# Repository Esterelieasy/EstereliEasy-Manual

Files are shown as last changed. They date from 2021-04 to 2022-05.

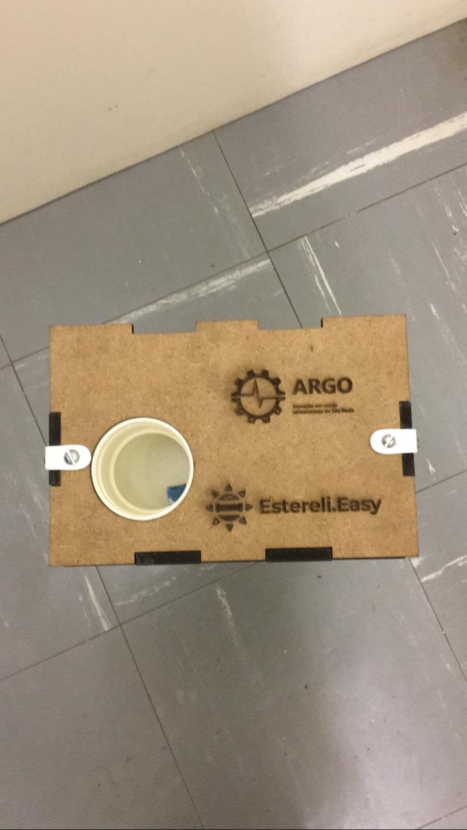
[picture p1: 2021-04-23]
Mídia/EstereliEasy3.jpeg

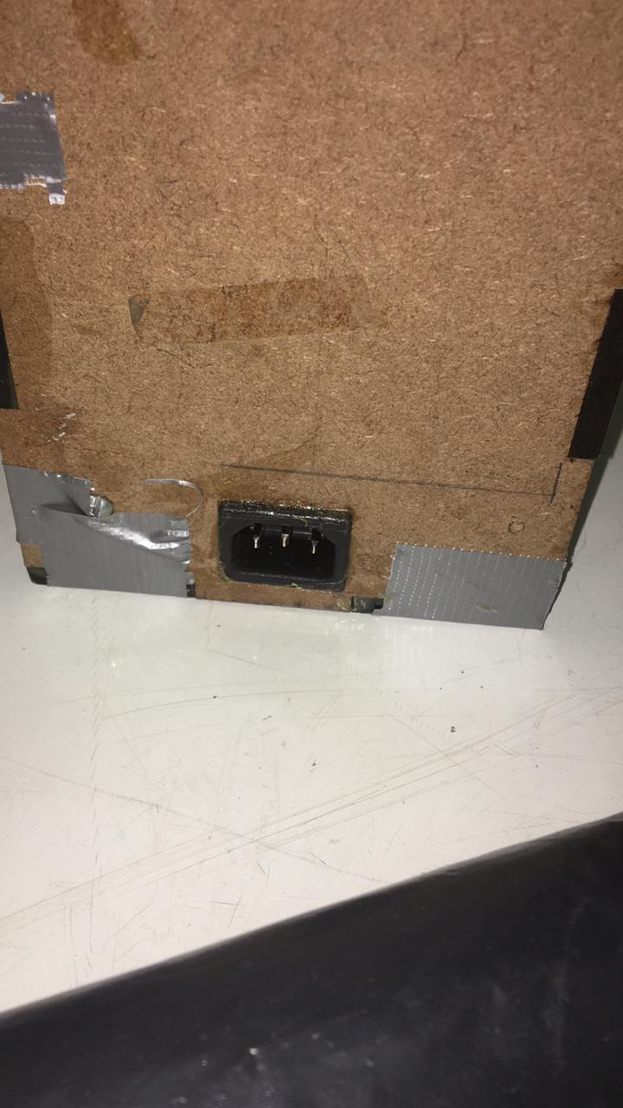
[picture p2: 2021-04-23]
Mídia/Esterelieasy4.jpeg

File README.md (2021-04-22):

# EstereliEasy-Manual
Repositório com informações de construção do nosso dispositivo.

Divisão das pastas:

* Arquivos - Cortadora: arquivos .dxf referentes às placas utilizadas para construção do equipamento.
* Parte Elétrica: imagens e arquivos referentes ao sistema eletrônico.
* Parte Mecânica: TO DO.
* Simulações: TO DO.
* Mídia: fotos e vídeos do protótipo.
* Manual: .pdf do Manual.

Link para conhecer o projeto: https://www.esterelieasy.com.br/

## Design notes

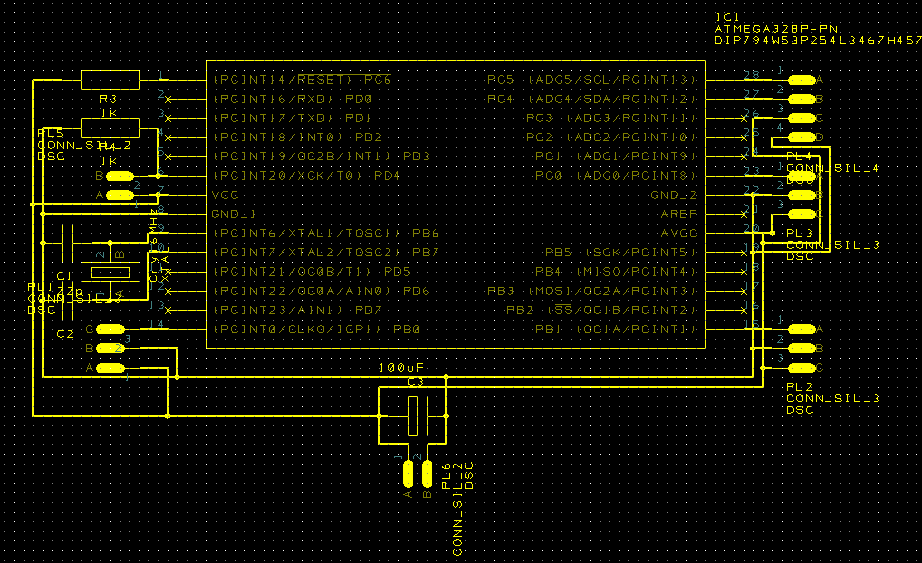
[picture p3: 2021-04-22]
Parte Elétrica/Captura de Tela (603).png

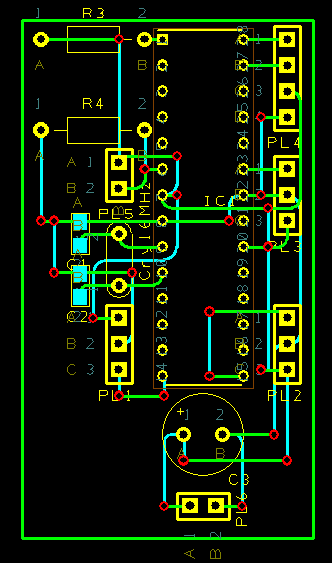
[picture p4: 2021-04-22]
Parte Elétrica/Captura de Tela (604).png

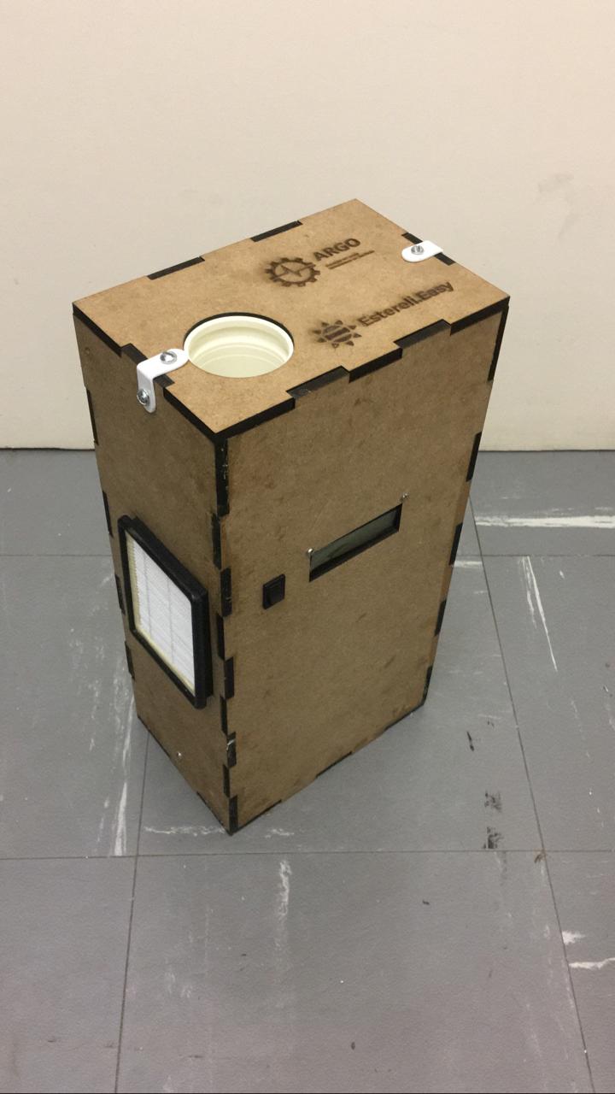
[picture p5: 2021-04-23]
Mídia/Esterelieasy1.jpeg

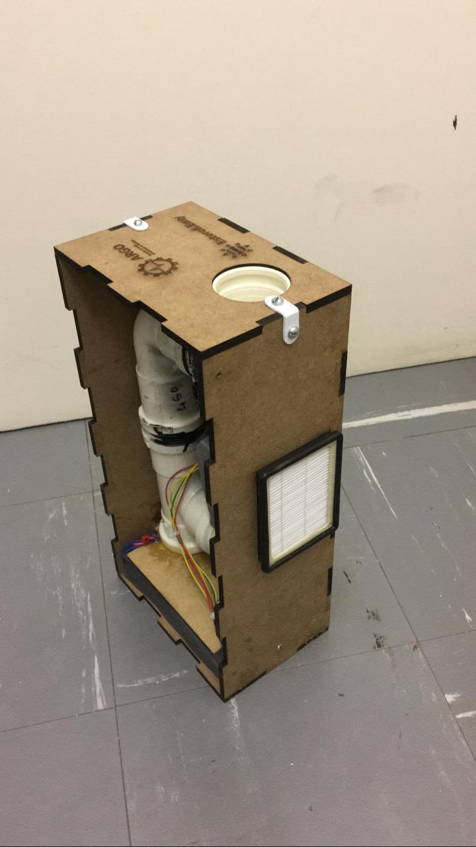
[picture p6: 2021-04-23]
Mídia/EstereliEasy2.jpeg

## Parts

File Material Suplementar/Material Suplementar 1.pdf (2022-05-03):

Material Suplementar 1

Cálculo de CADR

A equação (1) relaciona a concentração (C) com os parâmetros do ambiente:

dC
i
dt = S/V + Pλ
v

C

o − (λ

v + λ

d + λ
ac

)C
i | (1)

Onde C é a concentração interna do ambiente, S é a taxa de emissão de partícula, V é o
i
volume do quarto, P é o fator de penetração, λ taxa de infiltração do ar , é a concentração
v

C
o
externa, λ é a taxa de deposição na superfície e é a remoção causada pela limpeza do ar d λ
ac
(equipamento). Desconsiderando os termos de aumento da concentração e que a redução da concentração seja exclusivamente dada pelo equipamento, pode-se reescrever a equação (4) da seguinte maneira:

dC dt i = − λ C ac i

−λ t C (t) = C (0) e ac i i

C (0) −1 λ ac = ln i t C (t) i | (2)
Para calcular a razão | , pode-se expressar o número de partículas baseado na

C
i

(0)

C
i

(t)
seguinte expressão:

N(t + t
0

) = N(t) − Ne

'
(t)t

0 + Ns

'
(t)t
0

(3)

Onde N(t) é a quantidade de partículas no ambiente no instante t, N é a taxa de
e

'
(t)

partículas que entra no equipamento, N é a taxa de partículas que saem do dispositivo e
s

'
(t)

t é um intervalo de tempo. Considerando que o número de partículas pode ser definido pelo
0
produto entre sua concentração pelo seu volume e que a taxa de partículas que se movem pode ser calculado pelo produto entre concentração e fluxo, tem-se que a equação (5) pode ser reescrita da seguinte maneira:

C(t + t
0

)V = C(t)V − C(t)Qt

0 + kC(t)Qt
0

(4)

Onde k é a razão entre a concentração de saída pela entrada. Rearranjando os termos:

C(t + t
0

)V − C(t)V

t
0

= − C(t)Qt
0

(1 − k)
(5)

Aplicando limite de t até 0 em (7), tem-se que:
0

−1 ' C (t) = − C(t) Q t (1 − k)V 0

−1 t Q(1−k)V C(t) = C e 0 | (6)

Substituindo essa equação na equação (4), tem-se:

λ
ac
V = Q(1 − k ) | (7)
De acordo com (X), o produto λ | se chama CADR (Clean Air Delivery Rate), uma variável
ac

V

utilizada para verificar se o equipamento atende aos requisitos mínimos para limpeza de um ambiente. Para verificar a eficiência do equipamento em um cômodo de volume V, utiliza-se a equação abaixo:

ε =

CADR
V(λ

v + λ
d

) + CADR
(8)

É importante ressaltar que o valor de λ é influenciado pelo tamanho das partículas (
d

1, 0 ℎ

−1

para partículas de tamanho 2,5 μm), enquanto que λ possui valor próximo de | .
v

1, 0 ℎ

−1

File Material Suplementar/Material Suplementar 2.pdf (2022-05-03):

Material Suplementar 2

Estrutura para os testes microbiológicos

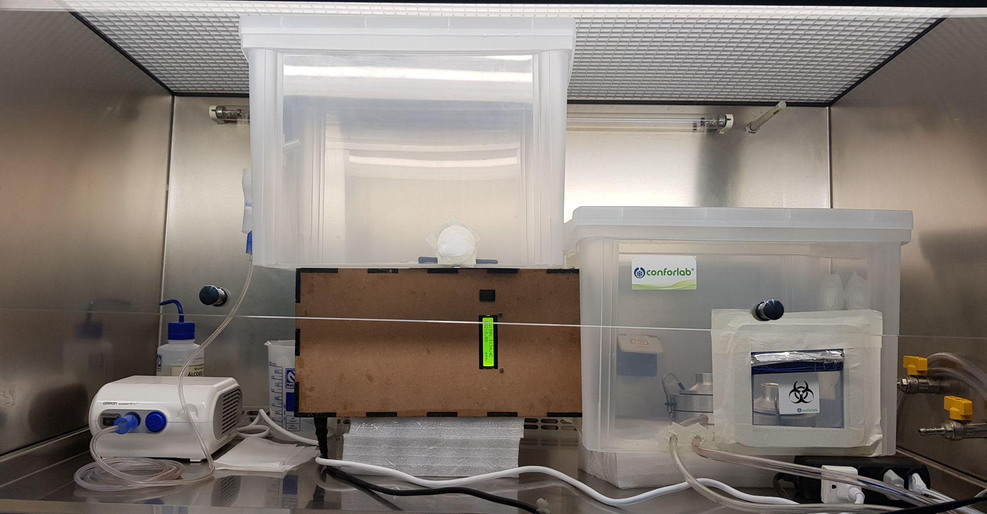
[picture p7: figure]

Figura 1: Montagem da estrutura para realização dos testes microbiológicos. O equipamento está em posição horizontal, conectado a uma célula de captação (acima na imagem) e a uma célula de exaustão (ao lado direito na imagem). Dentro da célula de exaustão foram posicionados dois amostradores de ar do tipo Andersen com placas de petri contendo meios de cultura seletivos. O nebulizador de compressor é da marca Omron, modelo NE-C28 e foi conectado à célula de captação.

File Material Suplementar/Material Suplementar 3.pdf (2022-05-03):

Material Suplementar 3

Cálculo da inativação viral

A equação utilizada para definir a inativação viral no ar está descrita abaixo ((BEGGS; AVITAL, 2020; BIASIN et al., 2021)): (https://sciwheel.com/work/citation?ids=11877962,9938325&pre=&pre=&suf=&suf=&sa=0,0)

N(t) = N(0) e

−ZEt | (1)

onde N(t) é a quantidade de vírus ativos no instante de tempo t, Z é a constante de suscetibilidade do vírus e E é a irradiância recebida. Adotando T como o tempo total que o vírus fica no equipamento, podemos modificar a equação (1) para a seguinte forma:

N(T)
N(0) = r = e
−ZD | (2)

onde r é a razão da quantidade de vírus ativos após a passagem no nosso equipamento sobre a quantidade inicial, ou seja, a taxa de inativação viral e Da dose total recebida (E⋅T). Em ((BEGGS; AVITAL, 2020; BIASIN et al., 2021)), (https://sciwheel.com/work/citation?ids=11877962,9938325&pre=&pre=&suf=&suf=&sa=0,0) são apresentados alguns valores de Z obtidos na literatura, sendo utilizado o valor de 0.20536 m²/J para estimar a taxa de inativação viral máxima do nosso equipamento.

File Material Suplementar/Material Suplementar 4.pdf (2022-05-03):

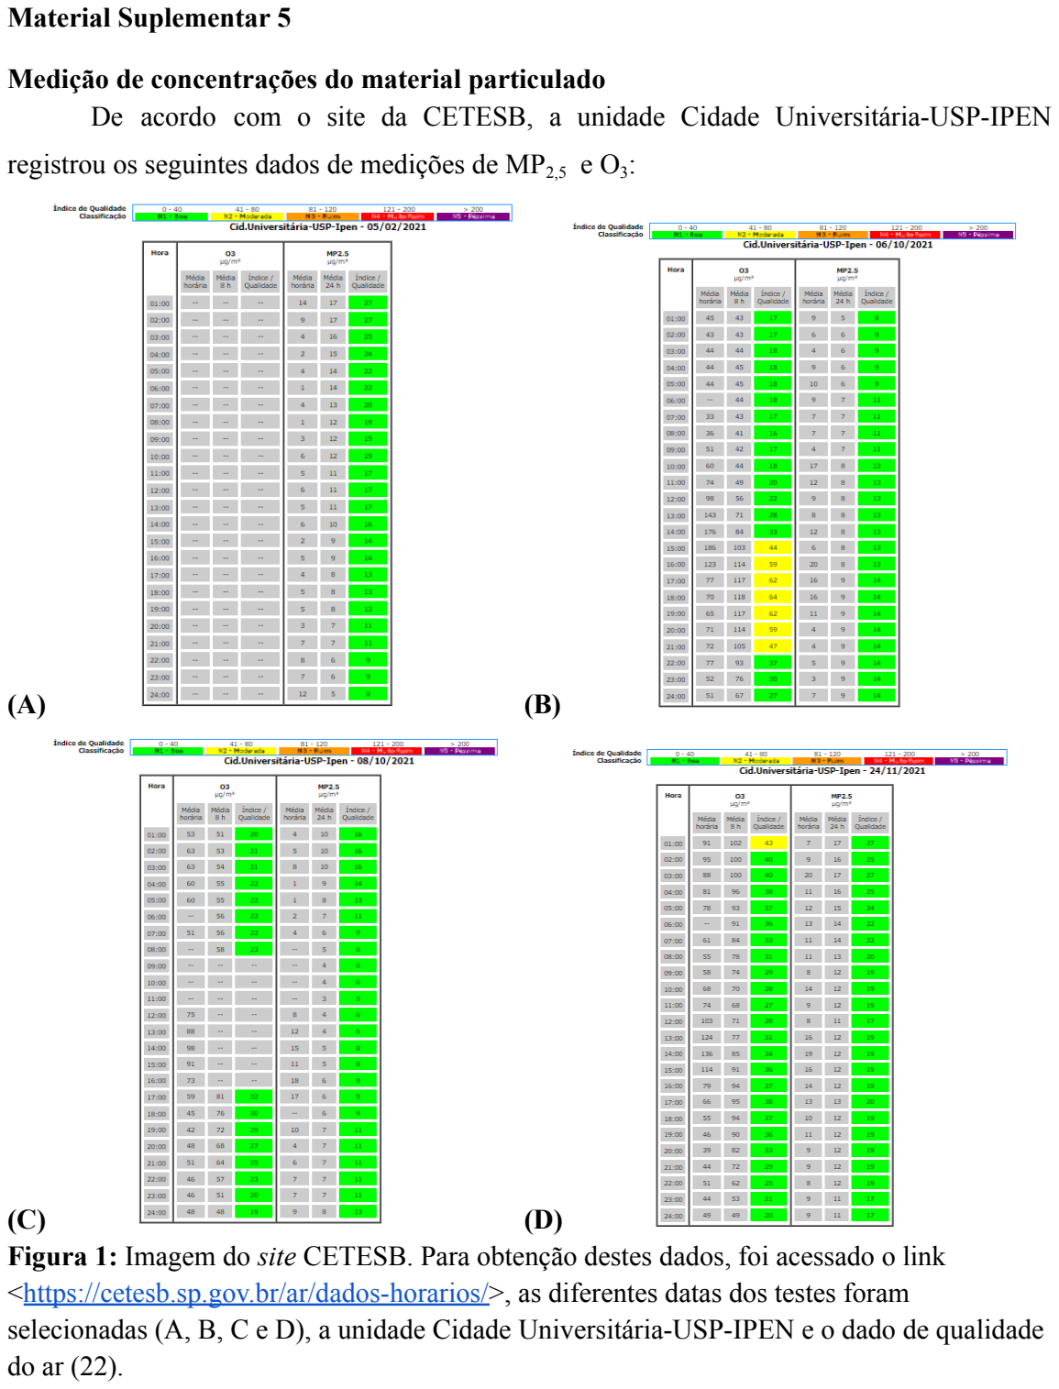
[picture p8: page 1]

Material Suplementar 5

Medição de concentrações do material particulado
De acordo com o site da CETESB, a unidade Cidade Universitária-USP-IPEN registrou os seguintes dados de medições de MP2,5 e O3

:

(A) (B)
(C) (D)
Figura 1: Imagem do site CETESB. Para obtenção destes dados, foi acessado o link <https://cetesb.sp.gov.br/ar/dados-horarios/>, as diferentes datas dos testes foram selecionadas (A, B, C e D), a unidade Cidade Universitária-USP-IPEN e o dado de qualidade do ar (22).

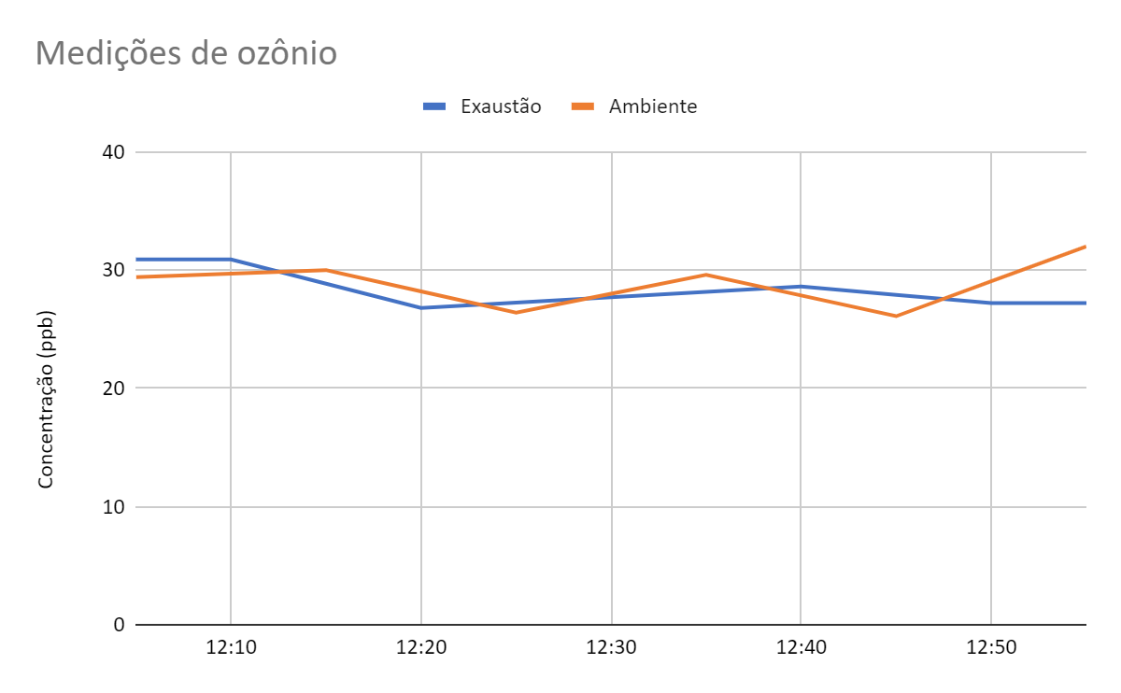
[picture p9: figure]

Figura 2. Concentrações de ozônio medidas na exaustão do purificador e no ambiente da sala (ppb).

Para a conversão dos valores obtidos, foi considerado que 1 ppb de ozônio equivale a 1.97 μg m⁻³
, nas condições de 25°C e 1 atm (21) na Tabela 1:

.Tabela 1: Conversão de unidades (ppb para μg m⁻³
).
| Externo | Interno
Média | 28,8 ppb= 56,6 μg m⁻³ | 28,3 ppb= 55,8 μg m⁻³

No primeiro experimento com o equipamento (realizado no dia 06/10/21), as concentrações externas de MP2,5 caíram muito entre 17h e 20h (variando entre 16 e 4 µg m⁻³ ;
Figura S4B) o que pode ter afetado as medições, que indicaram uma redução brusca nas concentrações ao longo do experimento, que podem estar mais associadas aos valores externos; contudo ligeiras reduções eram observada após períodos de 30 min com o equipamento ligado (I, II e III na Figura 3).

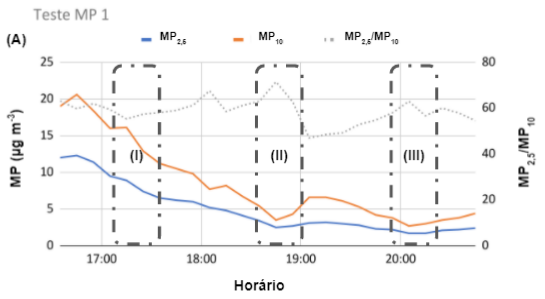
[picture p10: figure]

Figura 3. Medição da concentração em µg m⁻³ de MP2,5 e MP10 em função do tempo no primeiro teste realizado com o protótipo. As áreas numeradas dentro do retângulo representam os momentos após a ativação dos purificadores.

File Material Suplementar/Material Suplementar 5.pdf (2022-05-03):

Material Suplementar 6
Testes microbiológicos

Tabela 1: Valores obtidos a partir da coleta da superfície interna da caixa de amostragem e das partículas presentes no ar após nebulização de solução tampão fosfato (branco). Controle de Qualidade

Microrganismo Pesquisado | Superfície (UFC/Swab) | Análise do Ar (UFC/m³)
Fungos viáveis | menor que 1 | menor que 3
Bactérias mesófilas aeróbias | menos que 1 | menor que 3

Tabela 2: Valores de unidades formadoras de colônias dos três microrganismos testados: Staphylococcus aureus, Escherichia coli e Candida albicans, considerando: a quantidade inicial de solução adicionada no nebulizador (inóculo inicial); a quantidade presente na solução retida no aparelho nebulizador após a realização do teste (solução não nebulizada); a quantidade efetivamente nebulizada (solução nebulizada); a quantidade de microrganismos captada pelas duas placas de cultivo (Resultado - Placa 1 / Placa 2); e a quantidade de microrganismos que não foram coletados nos meios de cultura, ficando retidos na caixa (análise superfície interna da caixa de amostragem).
Dados experimentais
Microrganismo Testado | Inóculo inicial (UFC) | Solução não Nebulizada (UFC) | Solução Nebulizada (UFC) | Resultado - Placa 1 (UFC) | Resultado -Placa 2 (UFC) | Análise Superfície interna da caixa de amostragem (UFC/Swab)
Staphylococcus aureus (ATCC 6538) | 5,00E+05 | 8,15E+03 | 4,92E+05 | 1,35E+02 | 2,10E+02 | menor que 1
Escherichia coli (ATCC 8739) | 5,00E+05 | 5,70E+03 | 4,94E+05 | 2,10E+01 | 2,20E+01 | menor que 1
Candida albicans (ATCC 10231) | 5,00E+05 | 6,90E+03 | 4,93E+05 | 1,38E+02 | 1,23E+02 | menor que 1

Tabela 3: Valores de solução nebulizada e quantidade de microrganismos presentes no ar captados pelas placas presentes na caixa de amostragem corrigidos para UFC/m³. Com isso, foi possível calcular a porcentagem de redução de microrganismos após purificação pelo aparelho.

Eficácia do equipamento para material biológico

Microrganismo Testado | Inóculo nebulizado (UFC/m³) | Exaustão de Ar (m³/min) | Média dos Resultados (UFC) | Resultado dos amostradores (UFC/m³) | Redução (%)
Staphylococcus aureus ATCC 6538 | 89.476 | 0,55 | 1,73E+02 | 554 | 99,4%
Escherichia coli ATCC 8739 | 89.922 | 0,55 | 2,15E+01 | 69 | 99,9%
Candida albicans ATCC 10231 | 89.704 | 0,55 | 1,31E+02 | 419 | 99,5%

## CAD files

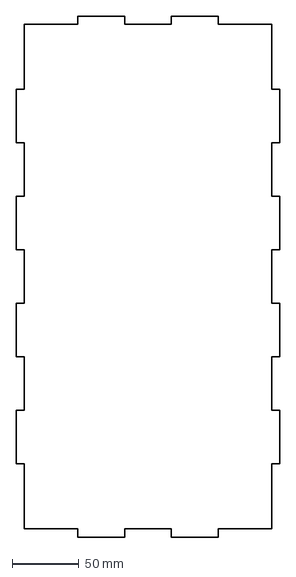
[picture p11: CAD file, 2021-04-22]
Arquivos - Cortadora/direita.dxf
197.0 x 390.0 mm

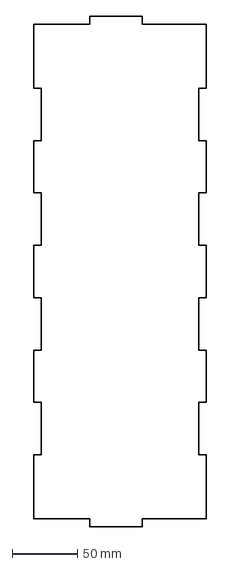
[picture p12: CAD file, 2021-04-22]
Arquivos - Cortadora/frente.dxf
132.0 x 390.0 mm

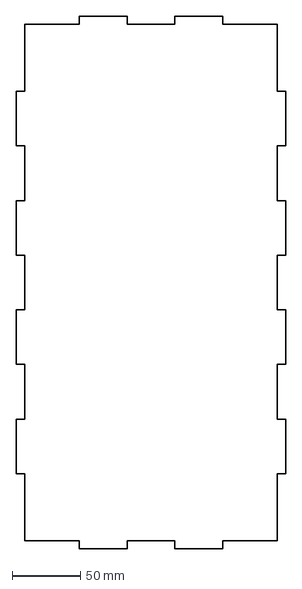
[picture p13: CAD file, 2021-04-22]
Arquivos - Cortadora/esquerda.dxf
197.0 x 390.0 mm

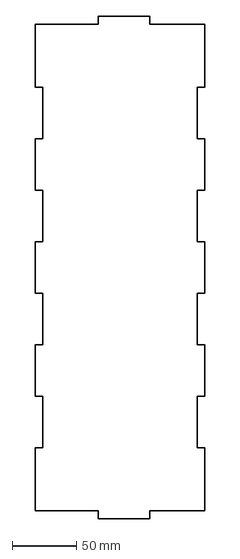
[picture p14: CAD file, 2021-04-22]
Arquivos - Cortadora/atras.dxf
132.0 x 390.0 mm

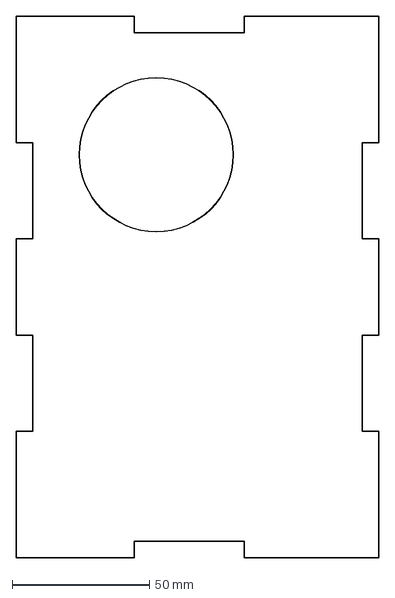
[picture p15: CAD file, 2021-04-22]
Arquivos - Cortadora/teto.dxf
132.0 x 197.0 mm

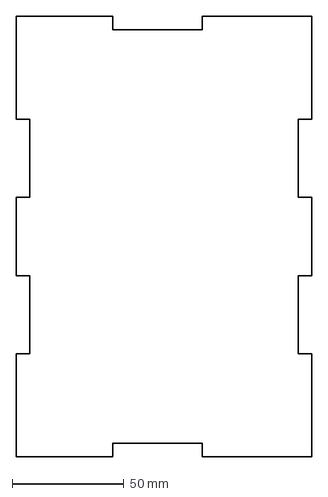
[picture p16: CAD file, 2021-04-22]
Arquivos - Cortadora/fundo.dxf
132.0 x 197.0 mm

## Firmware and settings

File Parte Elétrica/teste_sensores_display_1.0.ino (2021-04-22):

#include "MQ135.h"

#include <Wire.h>
#include <LiquidCrystal_I2C.h>
LiquidCrystal_I2C lcd(0x27,16,2);

#include "DHT.h"
#define DHTTYPE DHT11
DHT dht(9, DHTTYPE);

int val;
int sensorPin = A0;
int sensorValue = 0;
MQ135 gasSensor = MQ135(A0);

void setup() {
  Serial.begin(9600);
  lcd.init();
  dht.begin();
  pinMode(A0, INPUT); //MQ135
  pinMode(8, OUTPUT); //Rele
  pinMode(4, INPUT);  //Botao
}

void loop() {
  lcd.setBacklight(HIGH);

  int h = dht.readHumidity();
  float t = dht.readTemperature();

  MQ135 gasSensor = MQ135(A0); // Attach sensor to pin A0
  float rzero = gasSensor.getRZero();
  int sensorIn = A0;
  val = analogRead(A0);
  float ppm = gasSensor.getPPM()/100000000;

  if (t > 50){
    digitalWrite(8, LOW);
    lcd.setCursor(0,0);
    lcd.print("SUPERAQUECIMENTO");
    lcd.setCursor(2,1);
    lcd.print("DESLIGUE JA");
    delay(500);
    lcd.setCursor(0,0);
    lcd.print("                ");
    lcd.setCursor(0,1);
    lcd.print("                ");
  }
  else if (ppm > 2000){
    //digitalWrite(8, LOW);
    lcd.setCursor(1,0);
    lcd.print("EXCESSO DE CO2");
    lcd.setCursor(6,1);
    lcd.print("NO AR");
    delay(500);
    lcd.setCursor(0,0);
    lcd.print("                ");
    lcd.setCursor(0,1);
    lcd.print("                ");
  }
  else if (digitalRead(4) == 0){
    digitalWrite(8, LOW);
    lcd.setCursor(1,0);
    lcd.print("APERTE O BOTAO");
    lcd.setCursor(2,1);
    lcd.print("PARA INICIAR");
    delay(500);
    lcd.setCursor(0,0);
    lcd.print("                ");
    lcd.setCursor(0,1);
    lcd.print("                ");
  }else{
    digitalWrite(8, HIGH);
    lcd.setCursor(1,0);
    lcd.print("U:");
    lcd.setCursor(3,0);
    lcd.print(h);
    lcd.setCursor(5,0);
    lcd.print("%");
    lcd.setCursor(7,0);
    lcd.print("T:");
    lcd.setCursor(9,0);
    lcd.print(t);
    lcd.setCursor(13,0);
    lcd.print("C");
    lcd.setCursor(0,1);
    lcd.print("CO2:");
    lcd.setCursor(4,1);
    lcd.print(ppm); //MQ135 AIR QUALITY
    lcd.setCursor(12,1);
    lcd.print("ppm");
    delay(500);
  }
}

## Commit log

2021-04-22 Criada estrutura do github
    [atras.dxf, direita.dxf, esquerda.dxf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]
2022-05-03 Adicionado material suplementar
2022-05-05 Removendo Material
